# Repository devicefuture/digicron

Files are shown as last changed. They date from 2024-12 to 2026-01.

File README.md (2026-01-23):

# DigiCron
Software and hardware for the DigiCron smartwatch.

Want to try out the DigiCron's firmware in your browser? Just visit the [DigiCron Simulator](https://digicron.devicefuture.org/simulator)!

## Getting the code
You must clone this repo like this:

```bash
git clone --recurse-submodules https://github.com/devicefuture/digicron
```

`--recurse-submodules` must be used because this repo contains Git submodules which are used as libraries for the firmware and simulator.

## Building
Before building the firmware for the first time, you will need to install the development dependencies:

```bash
./build.sh --install-dev
```

To build the firmware and upload it to the target device over USB, run:

```bash
./build.sh --upload
```

You can also check for compilation errors without uploading by removing the `--upload` flag.

To build the firmware and the simulator, run:

```bash
./build.sh --sim
```

Then to run the simulator locally, you need to start a web server in this directory. You can run the following to start the web server at [localhost:8000](http://localhost:8000):

```bash
python3 -m http.server
```

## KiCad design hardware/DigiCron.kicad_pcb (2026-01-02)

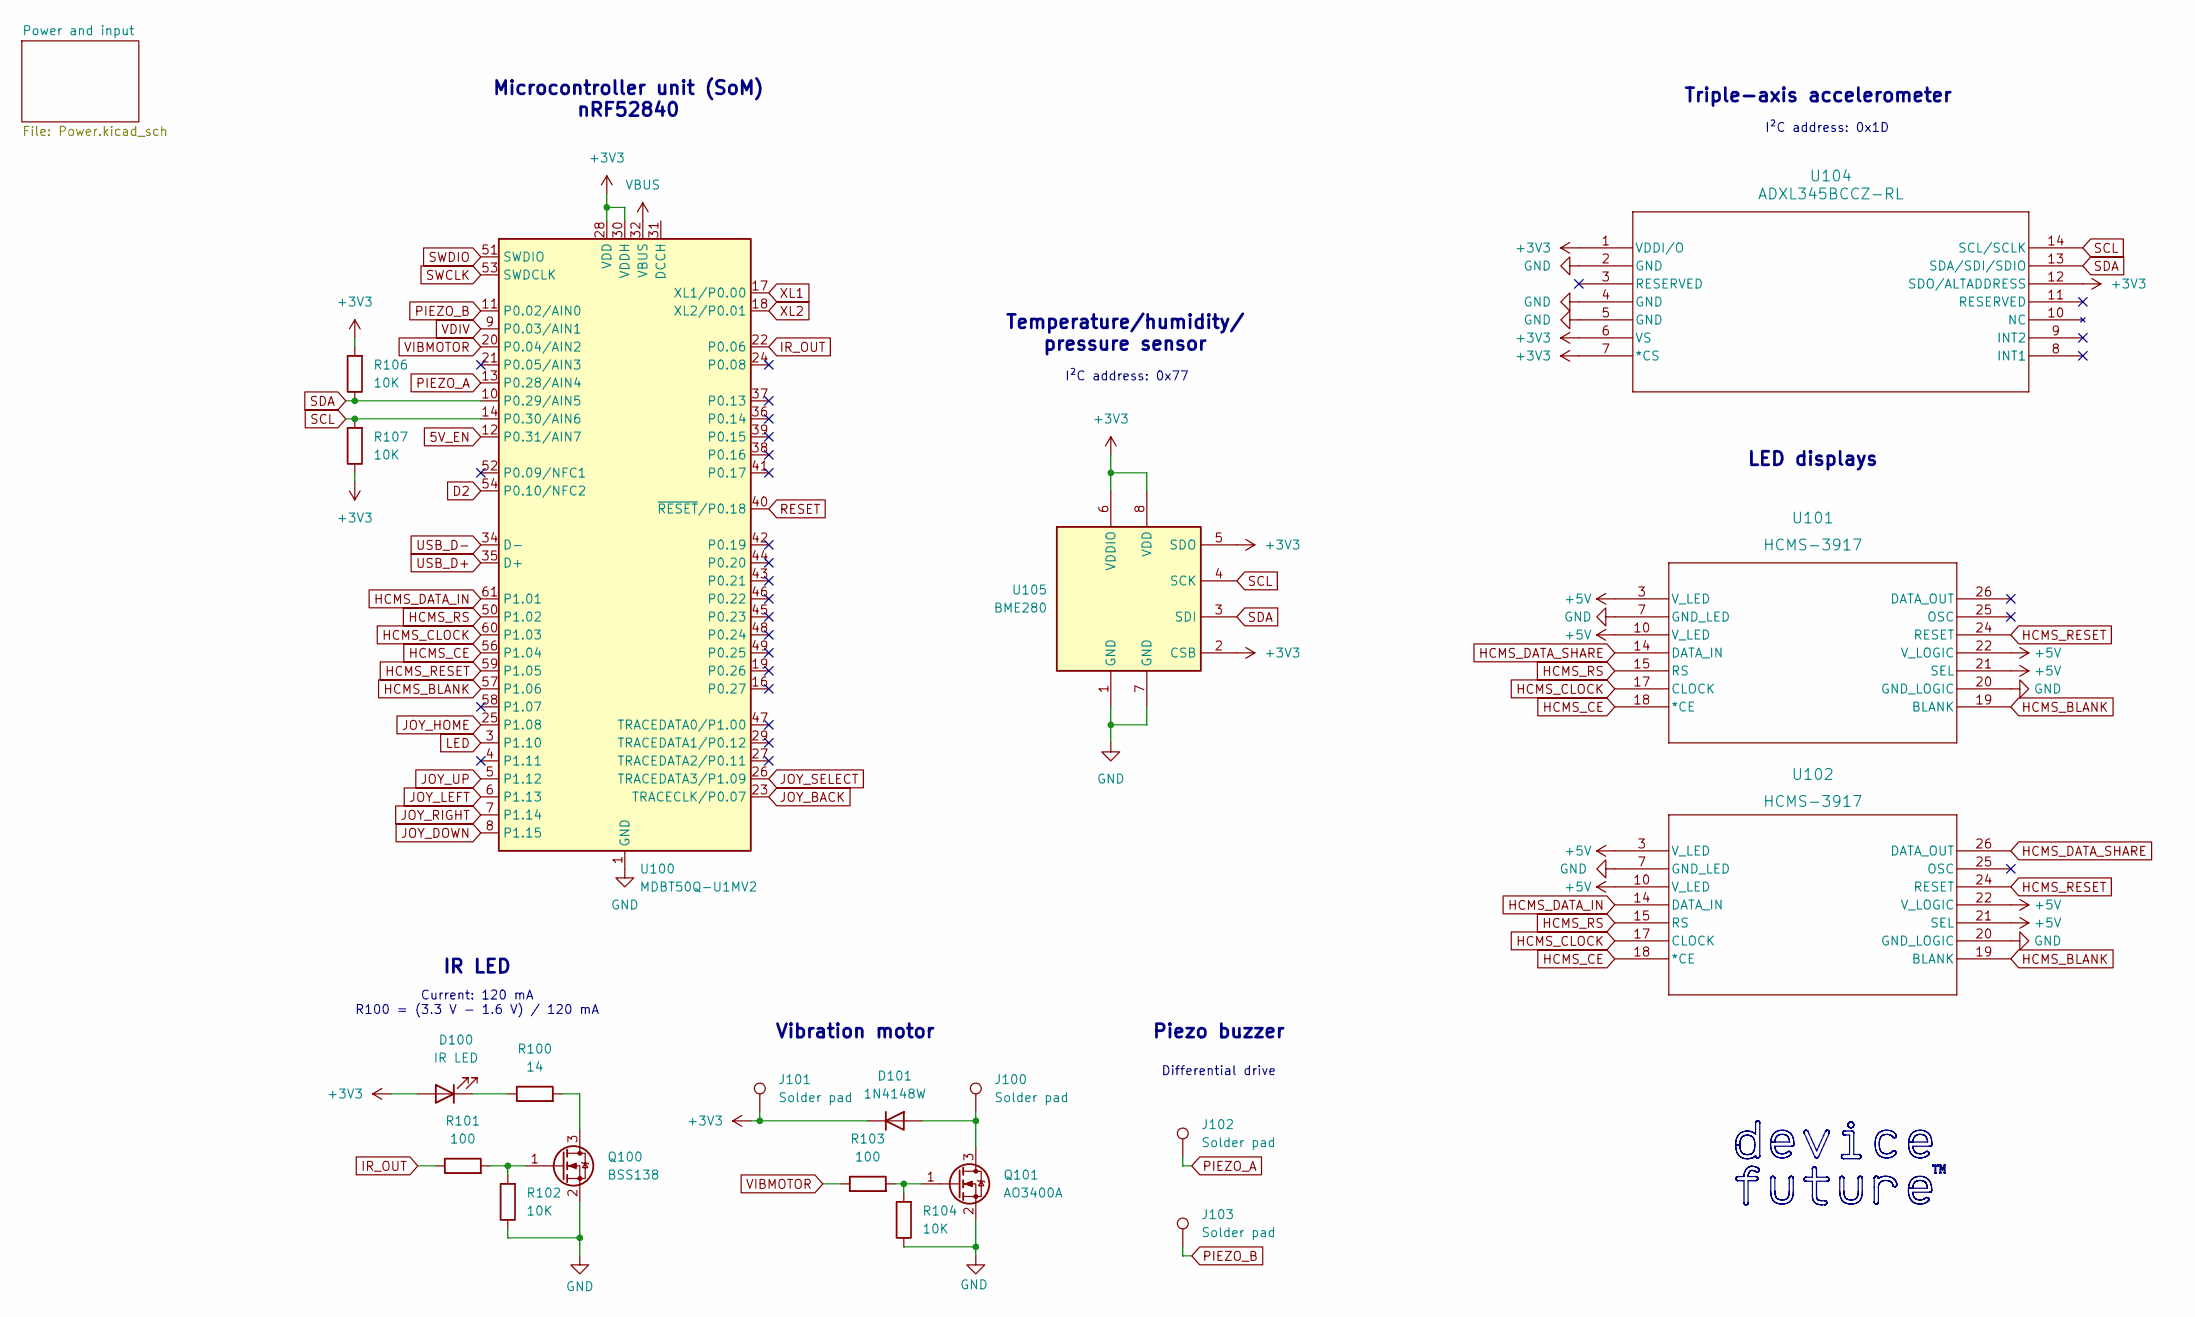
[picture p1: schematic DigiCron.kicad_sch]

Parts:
D100: IR LED; LED_D5.0mm_Horizontal_O1.27mm_Z3.0mm_IRBlack
D101: 1N4148W; D_SOD-123
J100, J101, J102, J103: Solder pad; SolderWirePad_1x01_SMD_1x2mm
Q100: BSS138; SOT-23
Q101: AO3400A; SOT-23
R100: 14; R_0402_1005Metric_Pad0.72x0.64mm_HandSolder
R101, R103: 100; R_0402_1005Metric_Pad0.72x0.64mm_HandSolder
R102, R104, R106, R107: 10K; R_0402_1005Metric_Pad0.72x0.64mm_HandSolder
U100: MDBT50Q-U1MV2; Raytac_MDBT50Q
U101, U102: HCMS-3917; DIP26_HCMS-290X-B_BRA
U104: ADXL345BCCZ-RL; LGA_CC-14-1_ADI
U105: BME280; Bosch_LGA-8_2.5x2.5mm_P0.65mm_ClockwisePinNumbering

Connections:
5V_EN: U100.12 (P0.31/AIN7); also elsewhere on the board
+3V3: D100.2 (A), D101.1 (K), J101.1, R106.2, R107.1, U100.28 (VDD), U100.30 (VDDH), U104.1 (VDDI/O), U104.6 (VS), U104.7 (*CS), U104.12 (SDO/ALTADDRESS), U105.2 (CSB), U105.5 (SDO), U105.6 (VDDIO), U105.8 (VDD); also elsewhere on the board
+5V: U101.3 (V_LED), U101.10 (V_LED), U101.21 (SEL), U101.22 (V_LOGIC), U102.3 (V_LED), U102.10 (V_LED), U102.21 (SEL), U102.22 (V_LOGIC); also elsewhere on the board
D2: U100.54 (P0.10/NFC2)
GND: Q100.2 (S), Q101.2 (S), R102.1, R104.1, U100.1 (GND), U100.2 (GND), U100.15 (GND), U100.33 (GND), U100.55 (GND), U101.7 (GND_LED), U101.20 (GND_LOGIC), U102.7 (GND_LED), U102.20 (GND_LOGIC), U104.2 (GND), U104.4 (GND), U104.5 (GND), U105.1 (GND), U105.7 (GND); also elsewhere on the board
HCMS_BLANK: U100.57 (P1.06), U101.19 (BLANK), U102.19 (BLANK)
HCMS_CE: U100.56 (P1.04), U101.18 (*CE), U102.18 (*CE)
HCMS_CLOCK: U100.60 (P1.03), U101.17 (CLOCK), U102.17 (CLOCK)
HCMS_DATA_IN: U100.61 (P1.01), U102.14 (DATA_IN)
HCMS_DATA_SHARE: U101.14 (DATA_IN), U102.26 (DATA_OUT)
HCMS_RESET: U100.59 (P1.05), U101.24 (RESET), U102.24 (RESET)
HCMS_RS: U100.50 (P1.02), U101.15 (RS), U102.15 (RS)
IR_OUT: R101.1, U100.22 (P0.06)
JOY_BACK: U100.23 (TRACECLK/P0.07); also elsewhere on the board
JOY_DOWN: U100.8 (P1.15); also elsewhere on the board
JOY_HOME: U100.25 (P1.08); also elsewhere on the board
JOY_LEFT: U100.6 (P1.13); also elsewhere on the board
JOY_RIGHT: U100.7 (P1.14); also elsewhere on the board
JOY_SELECT: U100.26 (TRACEDATA3/P1.09); also elsewhere on the board
JOY_UP: U100.5 (P1.12); also elsewhere on the board
LED: U100.3 (P1.10)
unnamed: D100.1 (K), R100.1
unnamed: D101.2 (A), J100.1, Q101.3 (D)
unnamed: Q100.3 (D), R100.2
unnamed: Q100.1 (G), R101.2, R102.2
unnamed: Q101.1 (G), R103.2, R104.2
PIEZO_A: J102.1, U100.13 (P0.28/AIN4)
PIEZO_B: J103.1, U100.11 (P0.02/AIN0)
RESET: U100.40 (~RESET/P0.18)
SCL: R107.2, U100.14 (P0.30/AIN6), U104.14 (SCL/SCLK), U105.4 (SCK)
SDA: R106.1, U100.10 (P0.29/AIN5), U104.13 (SDA/SDI/SDIO), U105.3 (SDI)
SWCLK: U100.53 (SWDCLK); also elsewhere on the board
SWDIO: U100.51 (SWDIO); also elsewhere on the board
USB_D+: U100.35 (D+); also elsewhere on the board
USB_D-: U100.34 (D-); also elsewhere on the board
VBUS: U100.32 (VBUS); also elsewhere on the board
VDIV: U100.9 (P0.03/AIN1); also elsewhere on the board
VIBMOTOR: R103.1, U100.20 (P0.04/AIN2)
XL1: U100.17 (XL1/P0.00); also elsewhere on the board
XL2: U100.18 (XL2/P0.01); also elsewhere on the board

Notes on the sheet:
Vibration motor
Temperature/humidity/ pressure sensor
I²C address: 0x77
LED displays
Triple-axis accelerometer
IR LED
Differential drive
I²C address: 0x1D
Piezo buzzer
Current: 120 mA R100 = (3.3 V - 1.6 V) / 120 mA
Microcontroller unit (SoM) nRF52840

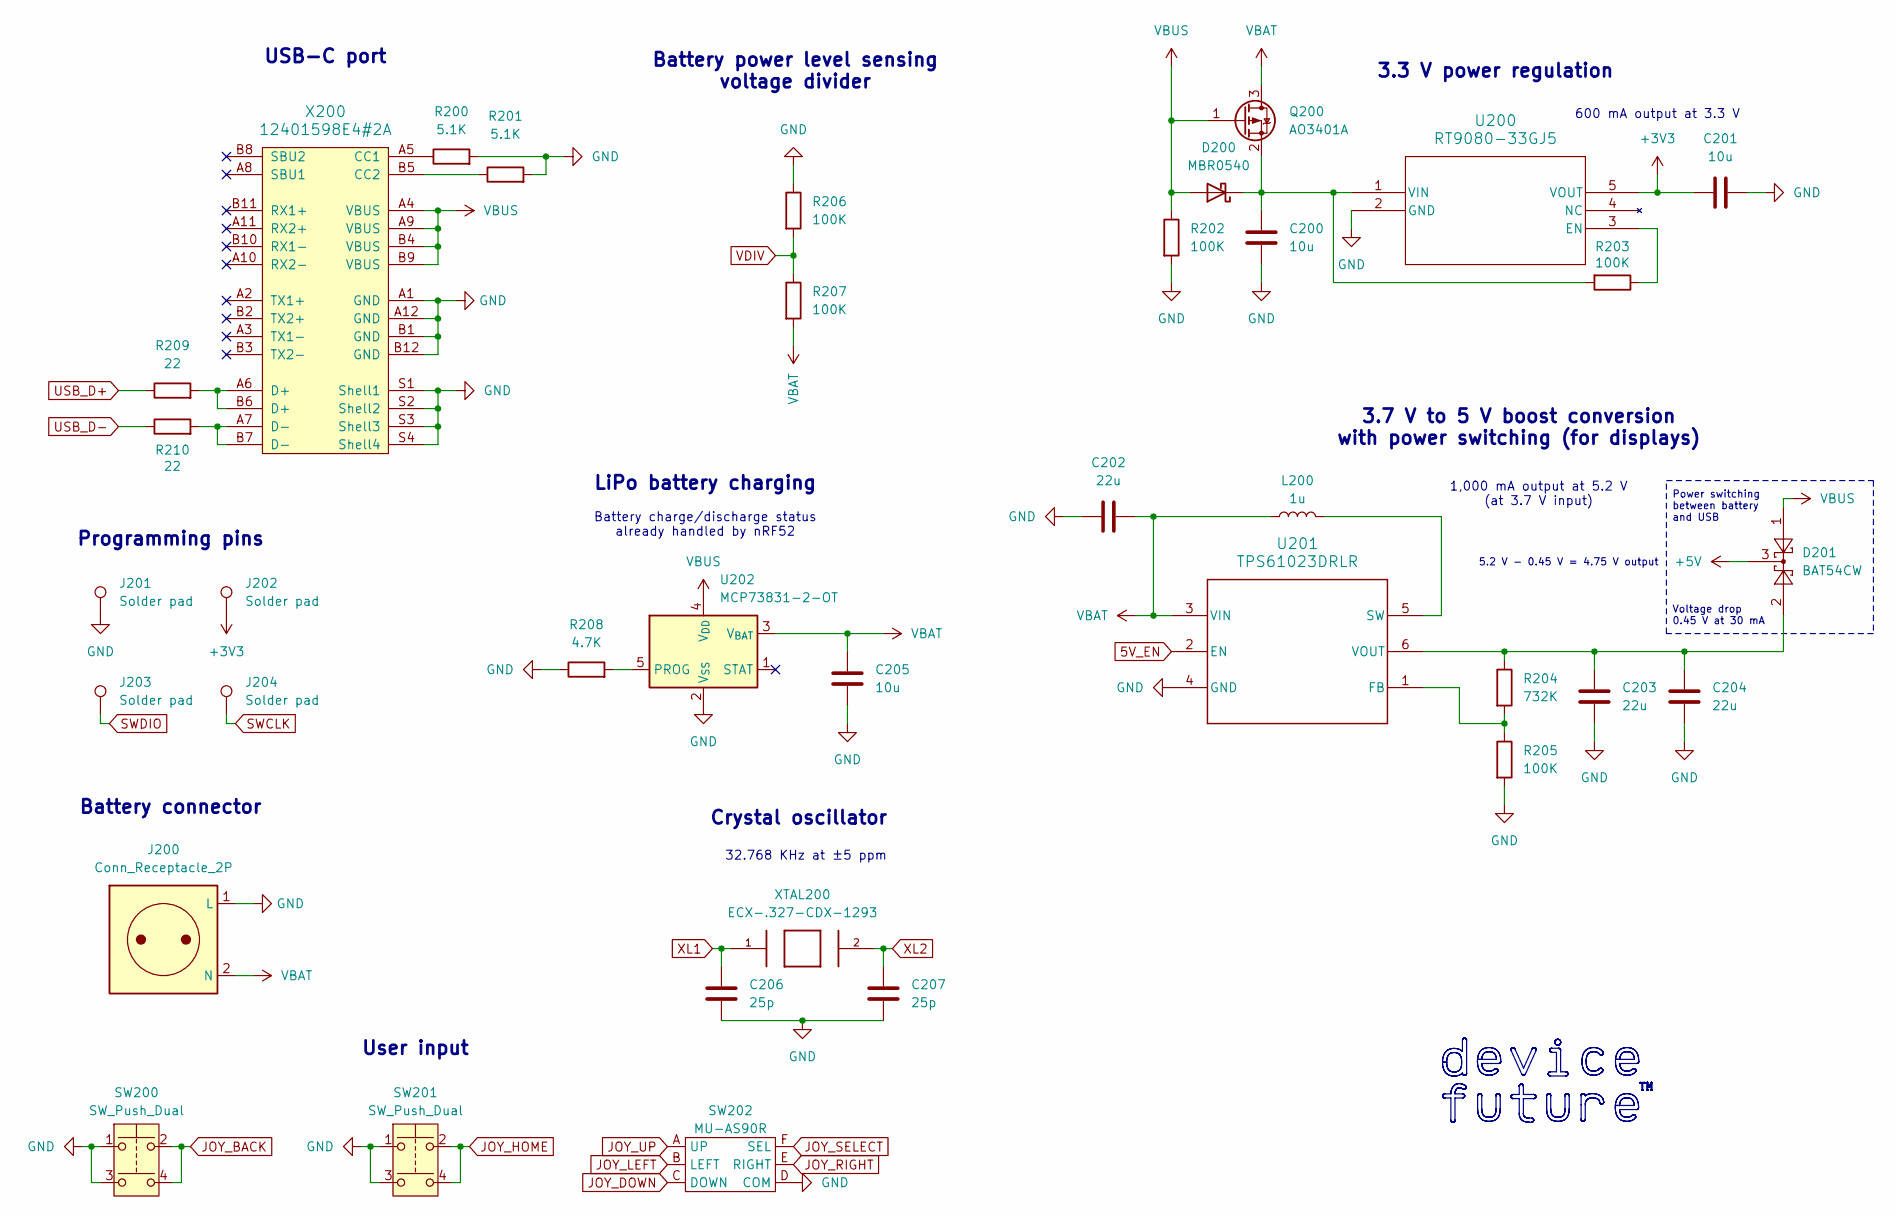
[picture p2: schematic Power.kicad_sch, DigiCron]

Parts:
C200, C201, C205: 10u; C_0402_1005Metric_Pad0.74x0.62mm_HandSolder
C202, C203, C204: 22u; C_0402_1005Metric_Pad0.74x0.62mm_HandSolder
C206, C207: 25p; C_0402_1005Metric_Pad0.74x0.62mm_HandSolder
D200: MBR0540; D_SOD-123
D201: BAT54CW; SOT-323_SC-70
J200: Conn_Receptacle_2P; Molex_PicoBlade_53261-0271_1x02-1MP_P1.25mm_Horizontal
J201, J202, J203, J204: Solder pad; TestPoint_Pad_2.0x2.0mm
L200: 1u; L_1008_2520Metric_Pad1.43x2.20mm_HandSolder
Q200: AO3401A; SOT-23-3L_AOS
R200, R201: 5.1K; R_0402_1005Metric_Pad0.72x0.64mm_HandSolder
R202, R203, R205, R206, R207: 100K; R_0402_1005Metric_Pad0.72x0.64mm_HandSolder
R204: 732K; R_0402_1005Metric_Pad0.72x0.64mm_HandSolder
R208: 4.7K; R_0402_1005Metric_Pad0.72x0.64mm_HandSolder
R209, R210: 22; R_0402_1005Metric_Pad0.72x0.64mm_HandSolder
SW200, SW201: SW_Push_Dual; SW_Push_1P1T_NO_6x6mm_H9.5mm
SW202: MU-AS90R
U200: RT9080-33GJ5; TSOT-23-5_RIT
U201: TPS61023DRLR; DRL0006A
U202: MCP73831-2-OT; SOT-23-5
X200: 12401598E4#2A
XTAL200: ECX-.327-CDX-1293; XTAL_ECS-.327-12.5-34RR-TR

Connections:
5V_EN: U201.2 (EN); also elsewhere on the board
+3V3: C201.1, J202.1, U200.5 (VOUT); also elsewhere on the board
+5V: D201.3; also elsewhere on the board
GND: C200.2, C201.2, C202.1, C203.2, C204.2, C205.2, C206.2, C207.2, J200.1 (L), J201.1, R200.2, R201.2, R202.2, R205.2, R206.1, R208.1, SW200.1, SW200.3, SW201.1, SW201.3, SW202.D (COM), U200.2 (GND), U201.4 (GND), U202.2 (V_{SS}), X200.A1 (GND), X200.A12 (GND), X200.B1 (GND), X200.B12 (GND), X200.S1 (Shell1), X200.S2 (Shell2), X200.S3 (Shell3), X200.S4 (Shell4); also elsewhere on the board
JOY_BACK: SW200.2, SW200.4; also elsewhere on the board
JOY_DOWN: SW202.C (DOWN); also elsewhere on the board
JOY_HOME: SW201.2, SW201.4; also elsewhere on the board
JOY_LEFT: SW202.B (LEFT); also elsewhere on the board
JOY_RIGHT: SW202.E (RIGHT); also elsewhere on the board
JOY_SELECT: SW202.F (SEL); also elsewhere on the board
JOY_UP: SW202.A (UP); also elsewhere on the board
unnamed: C200.1, D200.1 (K), Q200.2 (S), R203.2, U200.1 (VIN)
unnamed: R209.2, X200.A6 (D+), X200.B6 (D+)
unnamed: R210.2, X200.A7 (D-), X200.B7 (D-)
unnamed: R203.1, U200.3 (EN)
unnamed: R204.2, R205.1, U201.1 (FB)
unnamed: L200.2, U201.5 (SW)
unnamed: C203.1, C204.1, D201.2, R204.1, U201.6 (VOUT)
unnamed: R208.2, U202.5 (PROG)
unnamed: R200.1, X200.A5 (CC1)
unnamed: R201.1, X200.B5 (CC2)
SWCLK: J204.1; also elsewhere on the board
SWDIO: J203.1; also elsewhere on the board
USB_D+: R209.1; also elsewhere on the board
USB_D-: R210.1; also elsewhere on the board
VBAT: C202.2, C205.1, J200.2 (N), L200.1, Q200.3 (D), R207.2, U201.3 (VIN), U202.3 (V_{BAT})
VBUS: D200.2 (A), D201.1, Q200.1 (G), R202.1, U202.4 (V_{DD}), X200.A4 (VBUS), X200.A9 (VBUS), X200.B4 (VBUS), X200.B9 (VBUS); also elsewhere on the board
VDIV: R206.2, R207.1; also elsewhere on the board
XL1: C206.1, XTAL200.1; also elsewhere on the board
XL2: C207.1, XTAL200.2; also elsewhere on the board

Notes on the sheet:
Battery charge/discharge status already handled by nRF52
Programming pins
Crystal oscillator
600 mA output at 3.3 V
3.7 V to 5 V boost conversion with power switching (for displays)
32.768 KHz at ±5 ppm
1,000 mA output at 5.2 V (at 3.7 V input)
Power switching between battery and USB
Battery power level sensing voltage divider
Battery connector
LiPo battery charging
User input
5.2 V - 0.45 V = 4.75 V output
USB-C port
Voltage drop 0.45 V at 30 mA
3.3 V power regulation

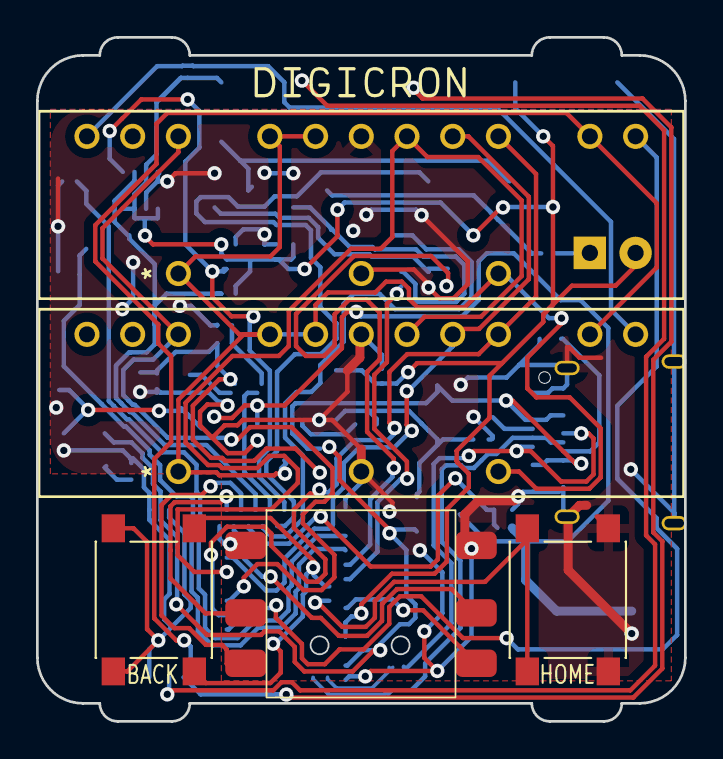
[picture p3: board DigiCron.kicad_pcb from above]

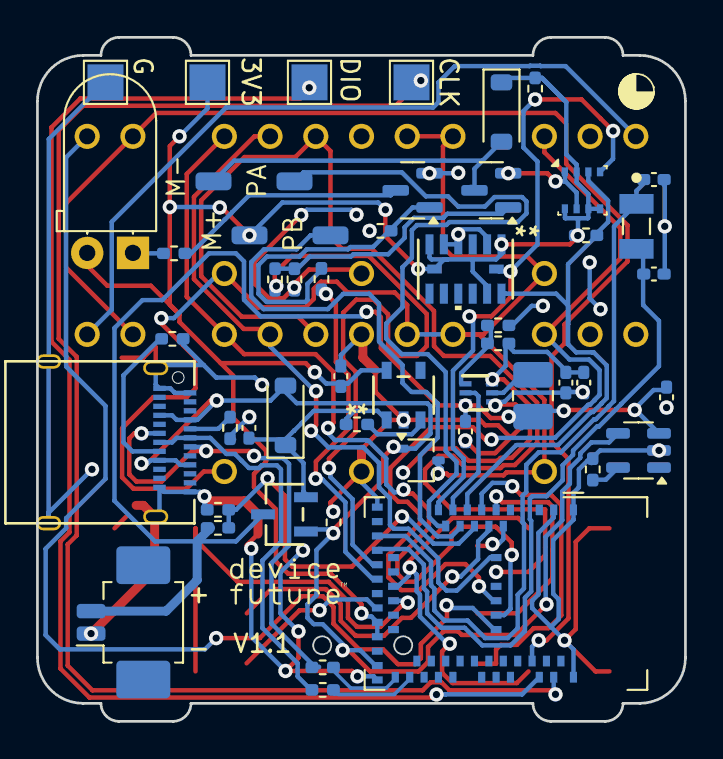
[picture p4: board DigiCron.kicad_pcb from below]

Board: 2 copper layers, 36.0 x 38.0 mm, 56 parts (51 on the bottom side), 48 nets.

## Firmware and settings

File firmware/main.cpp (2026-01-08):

#include <Arduino.h>

#ifndef DC_SIMULATOR
    #include <bluefruit.h>
    #include "HCMS39xx.h"
    #include "font5x7.h"
#else
    #include <emscripten.h>
    #include <stdio.h>
#endif

#include "datatypes.h"
#include "timing.h"
#include "power.h"
#include "display.h"
#include "ui.h"
#include "input.h"
#include "home.h"
#include "proc.h"
#include "fs.h"
#include "apps.h"
#include "bootanimation.h"
#include "_sysfs.h"

#define BACK_BTN_PIN 6
#define HOME_BTN_PIN 5
#define JOY_UP_PIN 10
#define JOY_DOWN_PIN 12
#define JOY_LEFT_PIN 9
#define JOY_RIGHT_PIN 11
#define JOY_SELECT_PIN 13

#define PROC_STEP_DURATION_US 1000

ui::Screen* startupScreen = new ui::Screen();

unsigned int displayMode = 0;
long lastTick = 0;
bool bootAnimationFinished = false;

#ifndef DC_SIMULATOR
    BLEDis bledis;
    BLEDfu bledfu;
#endif

void setup() {
    Serial.begin(115200);
    Serial.println("Hello, world!");
    Serial.flush();

    timing::init();
    display::init();
    input::init();

    ui::currentScreen = startupScreen;

    bootAnimation::start(startupScreen);

    ui::renderCurrentScreen();

    if (!fs::init()) {
        Serial.println("Failed to init filesystem");
        Serial.flush();

        while (true) {}
    }

    if (!sysfs::populate()) {
        Serial.println("Failed to populate sysfs");
        Serial.flush();

        while (true) {}
    }

    apps::scan();

    #ifndef DC_SIMULATOR
        Bluefruit.begin();
        Bluefruit.setTxPower(0);
        Bluefruit.setName("DigiCron");

        bledis.setModel("DeviceFuture DigiCron");
        bledis.setManufacturer("LiveG Technologies");
        bledis.begin();

        bledfu.begin();

        Bluefruit.Advertising.addFlags(BLE_GAP_ADV_FLAGS_LE_ONLY_GENERAL_DISC_MODE);
        Bluefruit.Advertising.addTxPower();
        Bluefruit.Advertising.addService(bledis);
        Bluefruit.Advertising.addService(bledfu);
        Bluefruit.ScanResponse.addName();
        Bluefruit.Advertising.setInterval(32, 244);
        Bluefruit.Advertising.setFastTimeout(30);
        Bluefruit.Advertising.start(10);

        while (true) {
            loop();
        }
    #endif
}

void loop() {
    long currentTick = timing::getCurrentTick();
    int difference = currentTick - lastTick;

    timing::earthTime.incrementTime(difference);

    lastTick = currentTick;

    if (bootAnimationFinished) {
        if (ui::currentScreen == startupScreen) {
            home::homeScreen.open(true);
        }
    } else {
        if (!bootAnimation::step() || input::getButtonStatus() == input::Button::BACK) {
            bootAnimationFinished = true;
        }
    }

    // #ifndef DC_SIMULATOR
    //     Serial.printf("Free heap: %d\r\n", dbgHeapFree());
    // #endif

    long startMicrosecond = timing::getCurrentMicrosecond();

    while (timing::getCurrentMicrosecond() - startMicrosecond < PROC_STEP_DURATION_US) {
        proc::stepProcesses();
    }

    ui::renderCurrentScreen();
}

#ifdef DC_SIMULATOR

int main(int argc, char** argv) {
    setup();

    emscripten_set_main_loop(loop, 0, true);

    return 0;
}

#endif

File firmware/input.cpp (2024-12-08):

#ifndef DC_SIMULATOR
    #include <Arduino.h>
#else
    #include <emscripten.h>
    #include <emscripten/bind.h>
#endif

#include "input.h"

#ifndef DC_SIMULATOR

#define BTN_BACK_PIN 6
#define BTN_HOME_PIN 5
#define JOY_UP_PIN 10
#define JOY_DOWN_PIN 12
#define JOY_LEFT_PIN 9
#define JOY_RIGHT_PIN 11
#define JOY_SELECT_PIN 13

void input::init() {
    pinMode(BTN_BACK_PIN, INPUT_PULLUP);
    pinMode(BTN_HOME_PIN, INPUT_PULLUP);
    pinMode(JOY_UP_PIN, INPUT_PULLUP);
    pinMode(JOY_DOWN_PIN, INPUT_PULLUP);
    pinMode(JOY_LEFT_PIN, INPUT_PULLUP);
    pinMode(JOY_RIGHT_PIN, INPUT_PULLUP);
    pinMode(JOY_SELECT_PIN, INPUT_PULLUP);
}

input::Button input::getButtonStatus() {
    if (digitalRead(BTN_BACK_PIN) == LOW) return Button::BACK;
    if (digitalRead(BTN_HOME_PIN) == LOW) return Button::HOME;
    if (digitalRead(JOY_UP_PIN) == LOW) return Button::UP;
    if (digitalRead(JOY_DOWN_PIN) == LOW) return Button::DOWN;
    if (digitalRead(JOY_LEFT_PIN) == LOW) return Button::LEFT;
    if (digitalRead(JOY_RIGHT_PIN) == LOW) return Button::RIGHT;
    if (digitalRead(JOY_SELECT_PIN) == LOW) return Button::SELECT;

    return Button::NONE;
}

#else

input::Button currentButton = input::Button::NONE;

void input::init() {}

input::Button input::getButtonStatus() {
    return currentButton;
}

void setButtonStatus(uint32_t button) {
    currentButton = (input::Button)button;
}

EMSCRIPTEN_BINDINGS(dc_input) {
    emscripten::function("input_setButtonStatus", setButtonStatus);
}

#endif

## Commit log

2024-09-07 Swap out display library for one with a licence
    [main.cpp]
2024-09-08 Get buttons and joystick working
2024-09-10 Add battery level and charge/discharge reporting
2024-09-11 Output battery voltage for testing
2024-09-11 Combine with `millis` to get millisecond precision
2024-09-14 Add string and icon printing for UI
2024-09-15 Add input buttons to simulator
2024-09-23 Add basic hardware schematic
    [DigiCron.kicad_pcb, DigiCron.kicad_sch]
2024-09-24 Use HCMS BLANK pin to prevent screen glitching
    [display.h]
2024-09-29 Fix running scheduler cycle on real hardware
    [main.cpp]
2024-12-11 Add some sensor ICs to schematic
    [DigiCron.kicad_pcb, DigiCron.kicad_sch]
2024-12-12 Replace BMP280 with BME280 and add IR LED and JST connector
    [DigiCron.kicad_pcb, DigiCron.kicad_sch]
2025-01-09 Overload `print` to support multiple types and add `pad` method for formatting numbers on display
2025-01-13 Add small note about uploading firmware to device
2025-01-14 Remove button testing code from home screen
2025-02-11 Debounce button input
2025-02-12 Replace displays with 5V versions (due to supply availability) and add power management ICs
    [DigiCron.kicad_pcb, DigiCron.kicad_sch, Power.kicad_sch]
2025-02-12 Remove KiCad backup files
2025-02-12 Change clearance to pass DRC for 0603 components
    [DigiCron.kicad_pcb]
2025-02-13 Modify 5V boost converter to use VBAT instead of 3V3 for input and add power switching circuit
    [DigiCron.kicad_pcb, DigiCron.kicad_sch, Power.kicad_sch]
2025-03-20 Add pads for wiring vibration motor and piezo buzzer
    [DigiCron.kicad_pcb, DigiCron.kicad_sch]
2025-03-22 Reposition USB port on board
    [DigiCron.kicad_pcb]
2025-03-25 Fix INI parser in config and add config reading demo to test app
    [fs.cpp]
2025-03-25 Fix memory issue when parsing INI files
    [main.cpp]
2025-03-25 Fix a few minor memory leaks
    [apps.cpp]
2025-03-27 Test FS directory listing and fix a few listing issues
    [fs.cpp]
2025-04-01 Allow reassignment of buttons in Counter app
2025-05-17 Make atto `print` command show text on screen
2025-05-20 Improve power sources for IR LED, vibration motor and piezo buzzer
    [DigiCron.kicad_pcb, DigiCron.kicad_sch]
2025-05-20 Reduce power consumption of IR LED
    [DigiCron.kicad_sch]
2025-05-21 Add voltage divider and replace boost converter
    [DigiCron.kicad_pcb, DigiCron.kicad_sch, Power.kicad_sch]
2025-05-21 Add notes about voltage drop at +5V power switching circuit
    [Power.kicad_sch]
2025-05-21 Add battery charging circuit
    [DigiCron.kicad_pcb, Power.kicad_sch]
2025-05-22 Make a few minor adjustments and add headings to schematic
    [DigiCron.kicad_pcb, DigiCron.kicad_sch, Power.kicad_sch]
2025-05-27 Add buttons to PCB layout
    [DigiCron.kicad_pcb, DigiCron.kicad_sch, Power.kicad_sch]
2025-05-27 Add joystick to PCB
    [DigiCron.kicad_pcb, Power.kicad_sch]
2025-05-27 Make a few tweaks to joystick on PCB
    [DigiCron.kicad_pcb]
2025-05-28 Add programming pins to PCB
    [DigiCron.kicad_pcb, Power.kicad_sch]
2025-05-28 Add crystal oscillator and hide designators from PCB
    [DigiCron.kicad_pcb, DigiCron.kicad_sch, Power.kicad_sch]
2025-05-29 Refactor atto bindings and add optional double buffering to `ui::Screen` class
    [screens.h]
2025-06-05 Fix freeing memory when replacing app process
    [screens.h]
2025-07-20 Perform PCB routing (WIP)
    [DigiCron.kicad_pcb, DigiCron.kicad_sch, Power.kicad_sch]
2025-07-20 Clean up some VBAT traces
    [DigiCron.kicad_pcb]
2025-07-20 Finish routing of PCB
    [DigiCron.kicad_pcb]
2025-07-24 Check over PCB design and re-add LTR390
    [DigiCron.kicad_pcb, DigiCron.kicad_sch]
2025-07-25 Add branding to back side of PCB
    [DigiCron.kicad_pcb]
2025-07-26 Add mounting tabs to edges of PCB
    [DigiCron.kicad_pcb, DigiCron.kicad_sch, Power.kicad_sch]
2025-07-26 Generate Gerber files
    [DigiCron-B_Cu.gbr, DigiCron-B_Mask.gbr, DigiCron-B_Paste.gbr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]
2025-07-26 Make minor alterations to not use custom font on PCB
    [DigiCron-B_Cu.gbr, DigiCron-B_Mask.gbr, DigiCron-B_Paste.gbr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]
2025-07-26 Update PCB to use 0402 resistor/capacitor packages
    [DigiCron-B_Cu.gbr, DigiCron-B_Mask.gbr, DigiCron-B_Paste.gbr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]
2025-08-11 Upgrade filesystem to fix issues when overwriting files
    [main.cpp]
2025-08-25 Allow apps to be force stopped by holding back button
2025-08-28 Add HTML BOM for PCB
2025-08-29 Fix a few resistor values on PCB relating to power management
    [DigiCron.kicad_pcb, DigiCron.kicad_sch, Power.kicad_sch]
2025-08-30 Make a few changes to footprint selection and resistor/capacitor values
    [DigiCron.kicad_pcb, DigiCron.kicad_sch, Power.kicad_sch]
2026-01-01 Reroute MCU pins to avoid vias inside pads
    [DigiCron.kicad_pcb]
2026-01-01 Remove LTR-390 to make assembly easier
    [DigiCron.kicad_pcb, DigiCron.kicad_sch]
2026-01-01 Fix pin routing for battery power level sensing
    [DigiCron.kicad_pcb, DigiCron.kicad_sch, Power.kicad_sch]
2026-01-01 Make minor routing tweak
    [DigiCron.kicad_pcb]
2026-01-01 Replace JST connector with PicoBlade 1.25 one
    [DigiCron.kicad_pcb, Power.kicad_sch]
2026-01-02 Fix minor routing error
    [DigiCron.kicad_pcb]
2026-01-02 Bump version number on PCB and schematics
    [DigiCron.kicad_pcb, DigiCron.kicad_sch, Power.kicad_sch]
2026-01-02 Make minor change to layout in schematic
    [DigiCron.kicad_sch]
